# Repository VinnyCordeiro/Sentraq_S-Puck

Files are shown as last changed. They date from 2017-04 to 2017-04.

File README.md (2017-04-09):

# Sentraq_S-Puck
Let's make an April's Fool prank true!

On April 1st, 2017, our friend Joshua Young from Sentraq announced the creation of the [Sentraq S-Puck keyboard](https://www.reddit.com/r/MechanicalKeyboards/comments/62wufr/teaser_sentraq_spuck/), a 21-switch circular keyboard.

But the joke is too good to let it restricted to an April's Fool prank, so I'm going to make it real!

All files of this repository are released in the public domain, go wild on them!

## Updates:
April 2, 2017: Released CAD files for sandwich-style 140mm diameter circular case (just a little bigger than a regular CD/DVD). Keep in mind that I've made them in about 30 minutes, it's possible there is something wrong with them. I've tested them with the Big Blue Saw online quote tool, though, and they should be fine. I'm designing to use M3 screws, they come with every computer case and are easy to source, you'll probable just need some M3 standoffs (the middle layers were designed with 8mm diameter standoffs in mind, you'll need to edit the files for other diameters). There is also the EAGLE files for a simple PCB; you will need an external controller to use it, like a Teensy 2.0 or an Arduino Micro. A version with embedded microcontroller is planned.

April 8, 2017: PCB with embedded microcontroller added. It can be programmed with both TMK and QMK firmwares. There's a Bill of Materials (BOM) included with Digi-Key codes for the components.

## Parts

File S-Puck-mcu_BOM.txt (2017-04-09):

Part  Value                      Device                                        Package                 Description            Digi-Key code
C1    4.7µ                       C-EUC0805K                                    C0805K                  CAPACITOR              1276-6462-1-ND
C2    1µ                         C-EUC0805K                                    C0805K                  CAPACITOR              311-1457-1-ND
C3,C4 8p                         C-EUC0805K                                    C0805K                  CAPACITOR              1276-2556-1-ND
JP1   USB-MB-H                   USB-MB-H                                      USB-MB-H                USB Connector          WM17115-ND
R1,R2 22                         R-US_R0805W                                   R0805W                  RESISTOR               RMCF0805JT22R0CT-ND
R3,R4 10k                        R-US_R0805W                                   R0805W                  RESISTOR               311-10KARCT-ND
S1                               10-XX                                         B3F-10XX                TACTILE SWITCH         679-2428-ND
U1    ATMEGA32U4-AU              ATMEGA32U4-AU                                 QFP80P1200X1200X120-44N 8-bit Microcontroller  ATMEGA32U4-AU-ND
Y1    16MHZ                      SMD-CRYSTAL-16MHZ-8PF-20PPM-40R(2P-5.0X3.2MM) X2-SMD-5.0X3.2X1.3MM    16MHz crystal          644-1187-2-ND

All diodes are standard, through hole 1N4148.

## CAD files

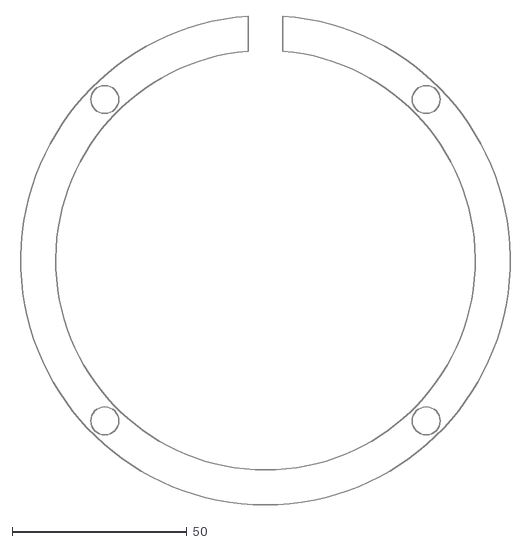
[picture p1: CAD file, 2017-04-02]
middle_cut_rev2.dxf
142.6 x 139.8

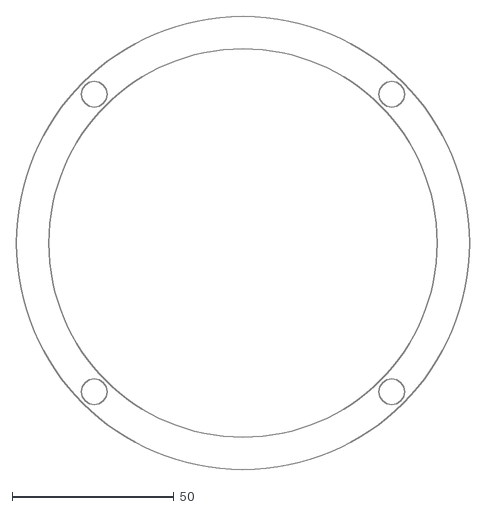
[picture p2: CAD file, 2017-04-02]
middle_rev2.dxf
140.0 x 140.0

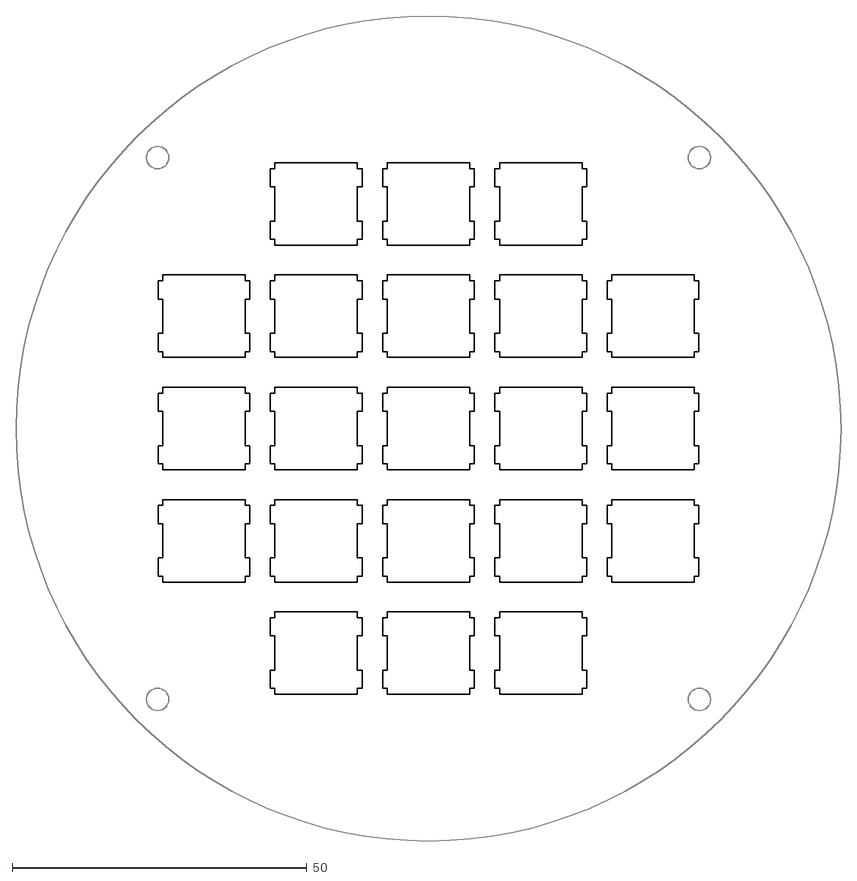
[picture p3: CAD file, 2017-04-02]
switch_rev4.dxf
140.0 x 140.0

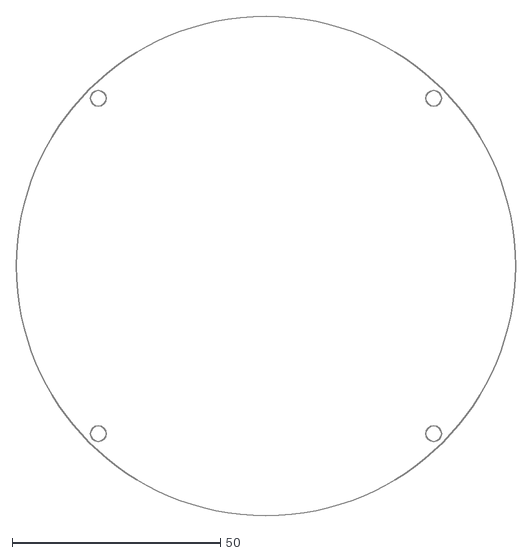
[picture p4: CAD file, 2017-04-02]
bottom_rev3.dxf
120.0 x 120.0

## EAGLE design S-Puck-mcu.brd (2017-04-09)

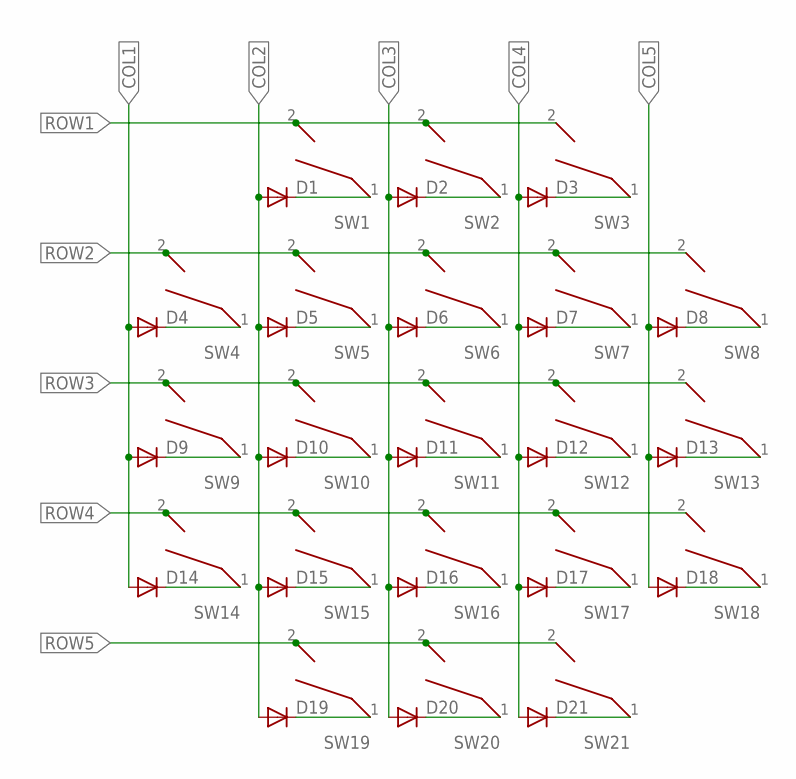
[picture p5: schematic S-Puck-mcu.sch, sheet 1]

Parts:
D1, D2, D3, D4, D5, D6, D7, D8, D9, D10, D11, D12, D13, D14, D15, D16, D17, D18, D19, D20, D21: 1N4148DO35-10; DO35-10
SW1, SW2, SW3, SW4, SW5, SW6, SW7, SW8, SW9, SW10, SW11, SW12, SW13, SW14, SW15, SW16, SW17, SW18, SW19, SW20, SW21: CHERRY_MX_WITH_FIXING_PINS; MX1A-XXNW

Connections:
COL1: D4.A, D9.A, D14.A; also elsewhere on the board
COL2: D1.A, D5.A, D10.A, D15.A, D19.A; also elsewhere on the board
COL3: D2.A, D6.A, D11.A, D16.A, D20.A; also elsewhere on the board
COL4: D3.A, D7.A, D12.A, D17.A, D21.A; also elsewhere on the board
COL5: D8.A, D13.A, D18.A; also elsewhere on the board
unnamed: D1.C, SW1.1
unnamed: D2.C, SW2.1
unnamed: D3.C, SW3.1
unnamed: D4.C, SW4.1
unnamed: D5.C, SW5.1
unnamed: D6.C, SW6.1
unnamed: D7.C, SW7.1
unnamed: D8.C, SW8.1
unnamed: D9.C, SW9.1
unnamed: D10.C, SW10.1
unnamed: D11.C, SW11.1
unnamed: D12.C, SW12.1
unnamed: D13.C, SW13.1
unnamed: D14.C, SW14.1
unnamed: D15.C, SW15.1
unnamed: D16.C, SW16.1
unnamed: D17.C, SW17.1
unnamed: D18.C, SW18.1
unnamed: D19.C, SW19.1
unnamed: D20.C, SW20.1
unnamed: D21.C, SW21.1
ROW1: SW1.2, SW2.2, SW3.2; also elsewhere on the board
ROW2: SW4.2, SW5.2, SW6.2, SW7.2, SW8.2; also elsewhere on the board
ROW3: SW9.2, SW10.2, SW11.2, SW12.2, SW13.2; also elsewhere on the board
ROW4: SW14.2, SW15.2, SW16.2, SW17.2, SW18.2; also elsewhere on the board
ROW5: SW19.2, SW20.2, SW21.2; also elsewhere on the board

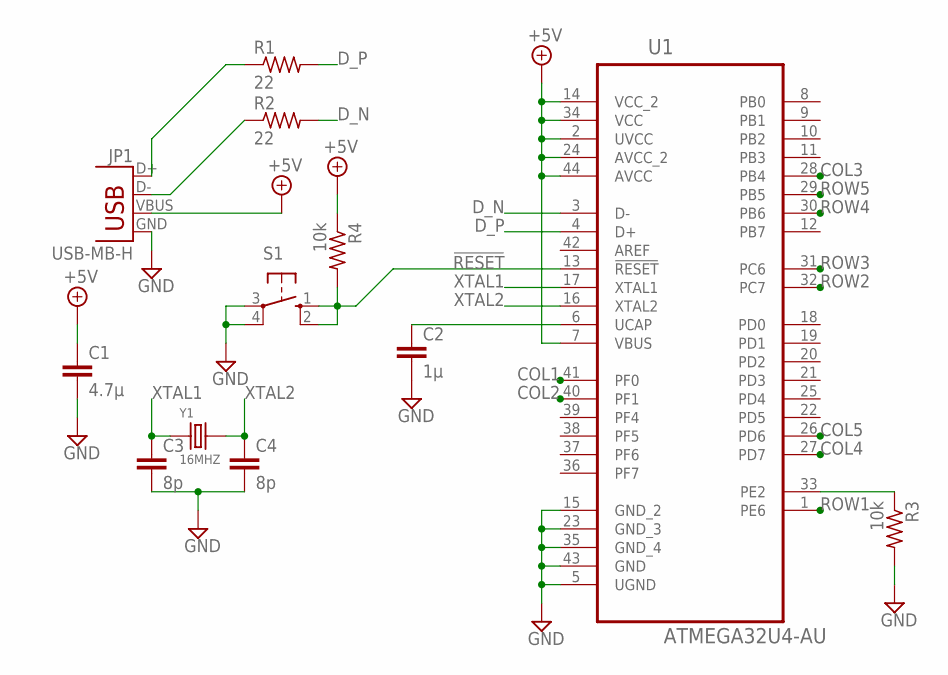
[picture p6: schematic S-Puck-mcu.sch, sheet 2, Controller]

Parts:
C1: 4.7µ; C0805K
C2: 1µ; C0805K
C3, C4: 8p; C0805K
JP1: USB-MB-H
R1, R2: 22; R0805W
R3, R4: 10k; R0805W
S1: 10-XX; B3F-10XX
U1: ATMEGA32U4-AU; QFP80P1200X1200X120-44N
Y1: 16MHZ; X2-SMD-5.0X3.2X1.3MM

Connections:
!RESET!: R4.2, S1.1 (S), S1.2 (S1), U1.13 (!RESET!)
+5V: C1.1, JP1.VBUS, R4.1, U1.2 (UVCC), U1.7 (VBUS), U1.14 (VCC_2), U1.24 (AVCC_2), U1.34 (VCC), U1.44 (AVCC)
COL1: U1.41 (PF0); also elsewhere on the board
COL2: U1.40 (PF1); also elsewhere on the board
COL3: U1.28 (PB4); also elsewhere on the board
COL4: U1.27 (PD7); also elsewhere on the board
COL5: U1.26 (PD6); also elsewhere on the board
D_N: R2.2, U1.3 (D-)
D_P: R1.2, U1.4 (D+)
GND: C1.2, C2.2, C3.2, C4.2, JP1.GND, R3.2, S1.3, S1.4 (P1), U1.5 (UGND), U1.15 (GND_2), U1.23 (GND_3), U1.35 (GND_4), U1.43 (GND)
unnamed: JP1.D+, R1.1
unnamed: JP1.D-, R2.1
unnamed: R3.1, U1.33 (PE2)
unnamed: C2.1, U1.6 (UCAP)
ROW1: U1.1 (PE6); also elsewhere on the board
ROW2: U1.32 (PC7); also elsewhere on the board
ROW3: U1.31 (PC6); also elsewhere on the board
ROW4: U1.30 (PB6); also elsewhere on the board
ROW5: U1.29 (PB5); also elsewhere on the board
XTAL1: C3.1, U1.17 (XTAL1), Y1.1
XTAL2: C4.1, U1.16 (XTAL2), Y1.2

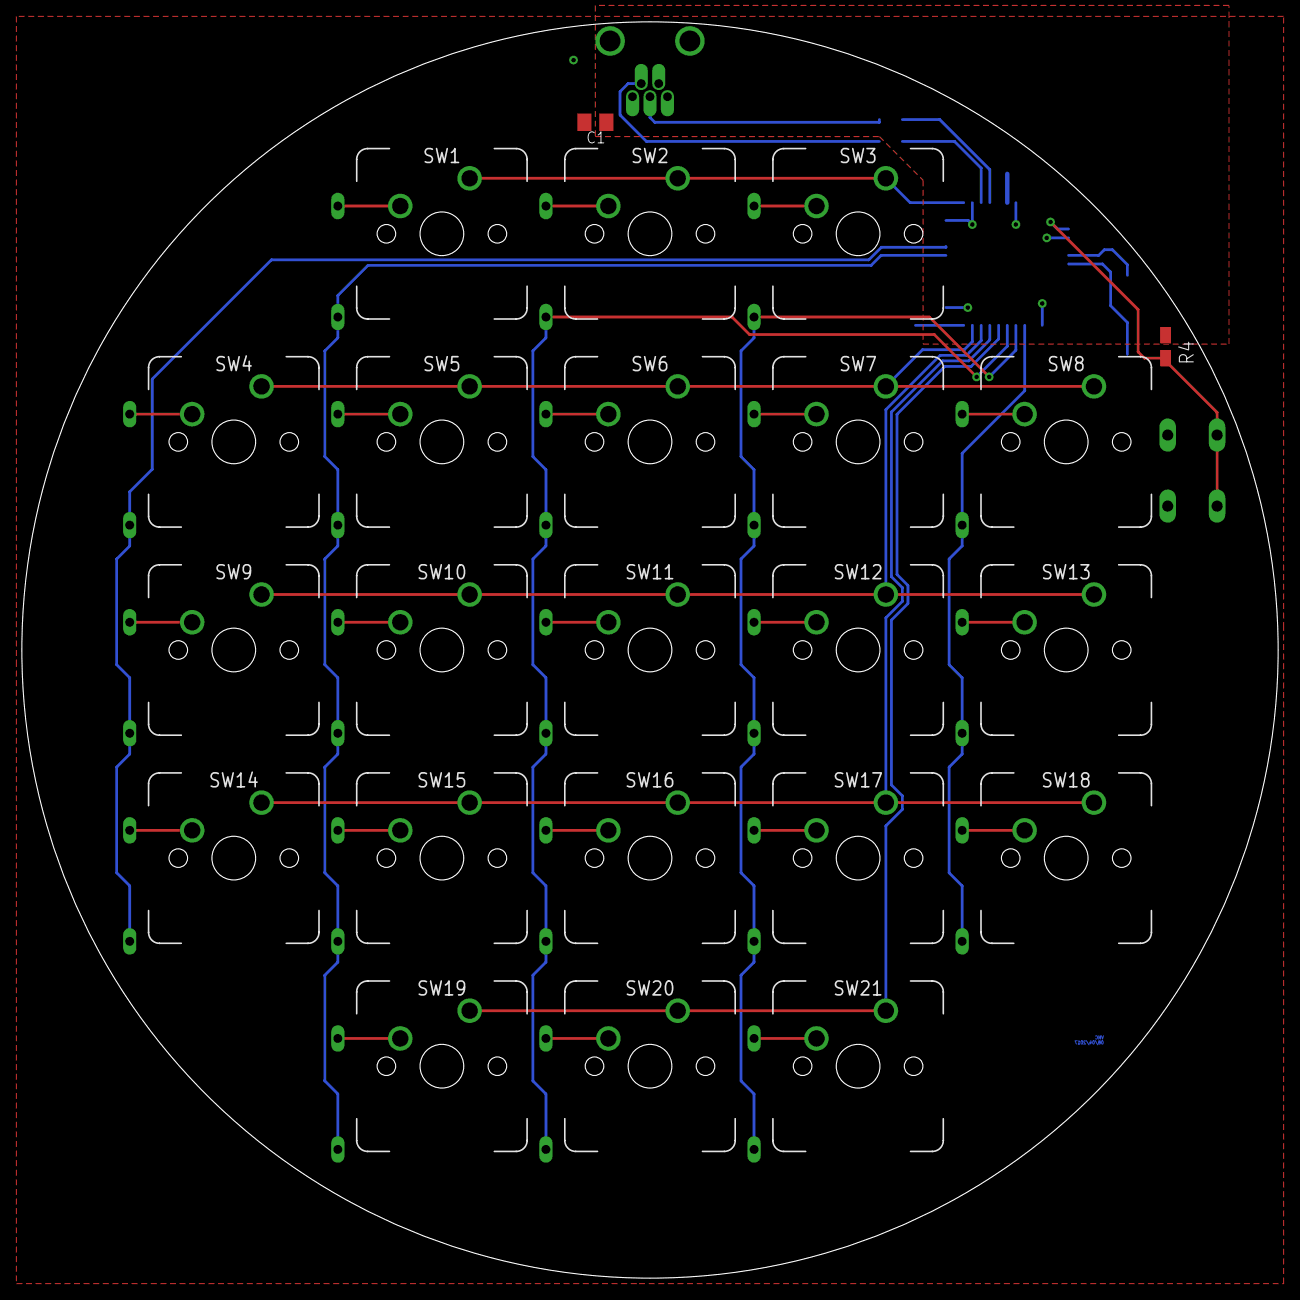
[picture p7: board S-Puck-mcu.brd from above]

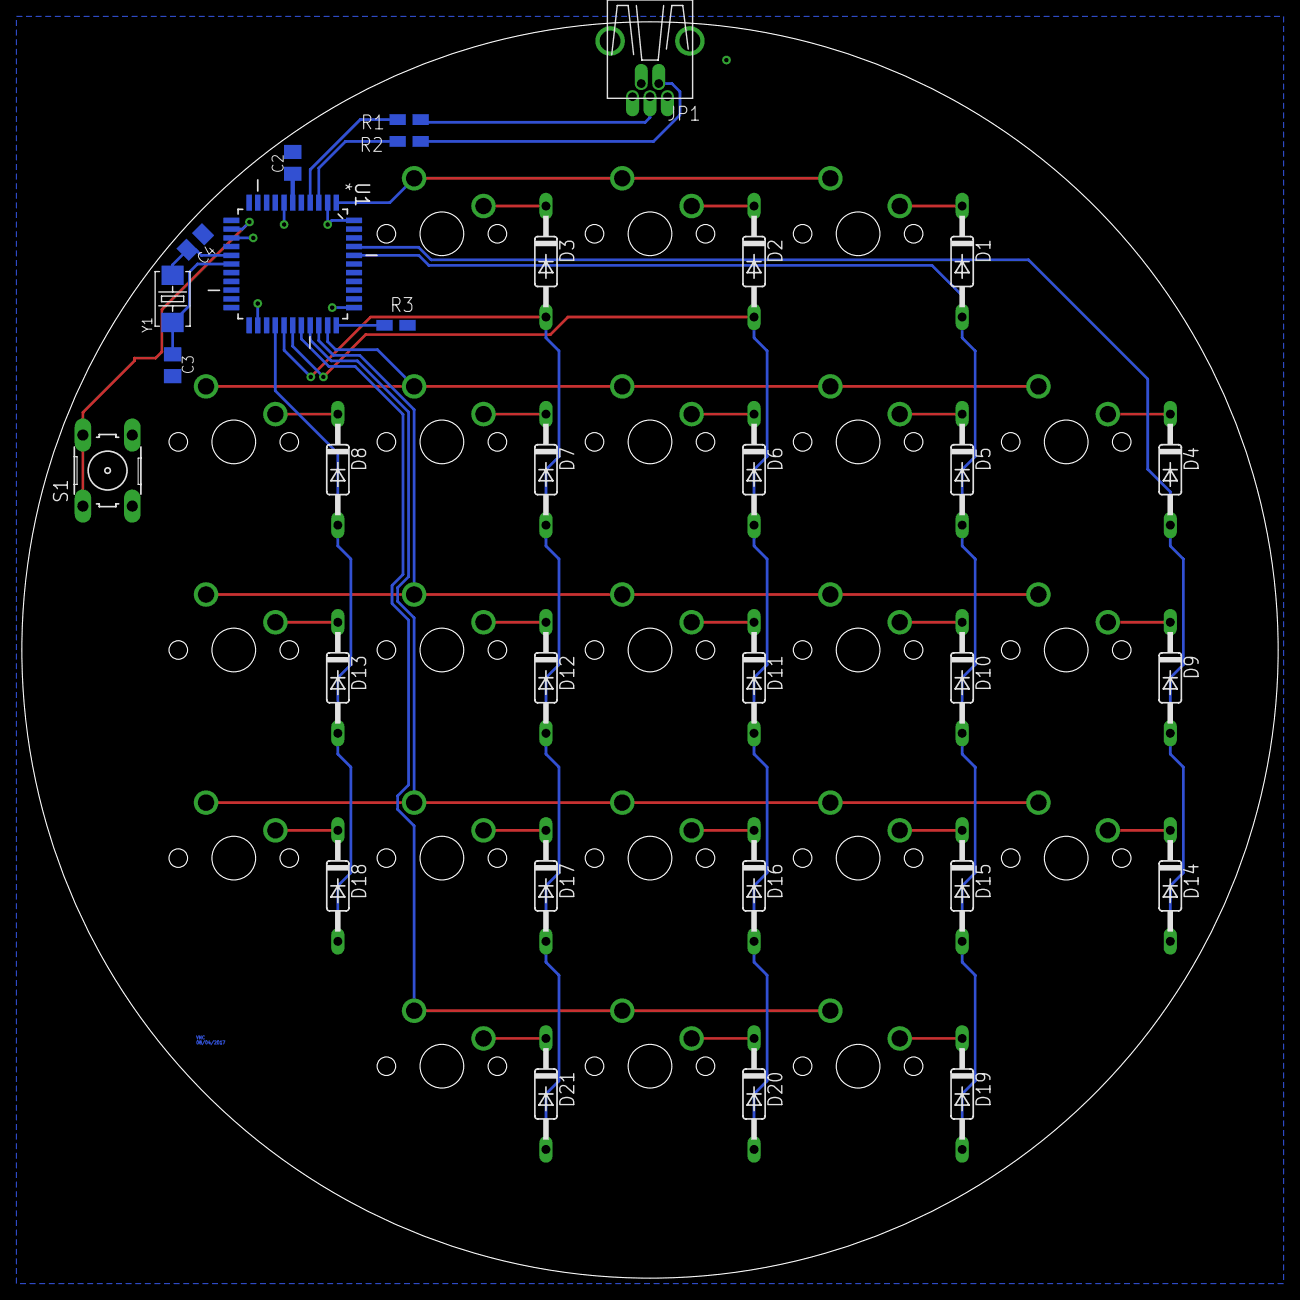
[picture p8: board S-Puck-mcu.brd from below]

Board: 2 copper layers, 115.0 x 115.0 mm, 54 parts (31 on the bottom side), 42 nets.

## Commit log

2017-04-02 Initial commit
    Switch and bottom plates for a sandwich-style case. Designed to use M3 screws.
    [bottom_rev3.dxf, switch_rev4.dxf]
2017-04-02 Updated CAD files
    Increased size of the case to 140mm diameter, due to fitting problems with the upcoming PCB. Also added middle layers, with and without cutout for USB connector.
    [middle_cut_rev2.dxf, middle_rev2.dxf, switch_rev4.dxf]
2017-04-02 Update README.md
    Changed the size of the case, from 120mm to 140mm in diameter.
2017-04-02 No microcontroler PCB
    First version of a PCB for the S-Puck. This PCB requires an external board, like a Teensy 2.0.
    [S-Puck-no_mcu.brd, S-Puck-no_ncu.sch]
2017-04-02 Update README.md
    Added information about the PCB.
2017-04-02 Rename S-Puck-no_ncu.sch to S-Puck-no_mcu.sch
    Correcting a typo.
    [S-Puck-no_mcu.sch]
2017-04-09 PCB with embedded microcontroller
    This PCB uses an ATmega32U4 microcontroller that can be programmed with TMK or QMK firmwares.
    [S-Puck-mcu.brd, S-Puck-mcu.sch]
2017-04-09 Added Bill of Materials (BOM)

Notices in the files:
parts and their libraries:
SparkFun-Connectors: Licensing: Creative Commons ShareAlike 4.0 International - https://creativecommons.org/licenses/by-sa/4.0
